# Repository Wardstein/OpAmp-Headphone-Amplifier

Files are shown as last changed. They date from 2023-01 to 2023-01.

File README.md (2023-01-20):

# Headphone Amplifier with 24bit DAC
A (massive) parallel OpAmp headphone amplifier using 16 parallel OpAmps per channel. The complete box has three PCBs: the power supply, a 24bit DAC with USB interface and the amplifier board itself (hidden under the black heatsink).

<p float="center">
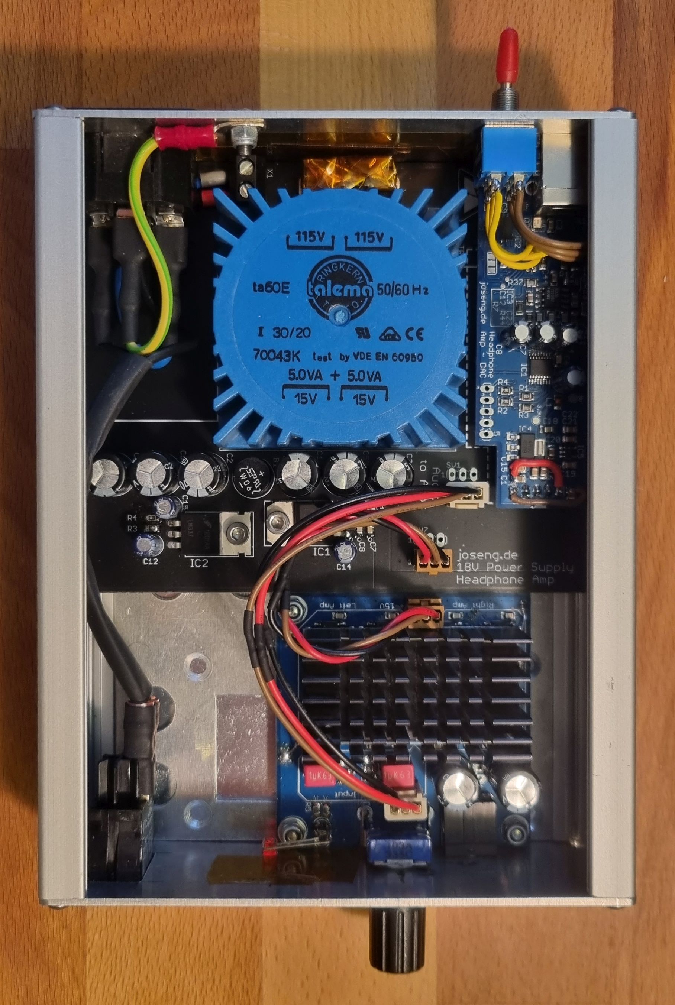
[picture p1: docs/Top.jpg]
Amplifier Top
  
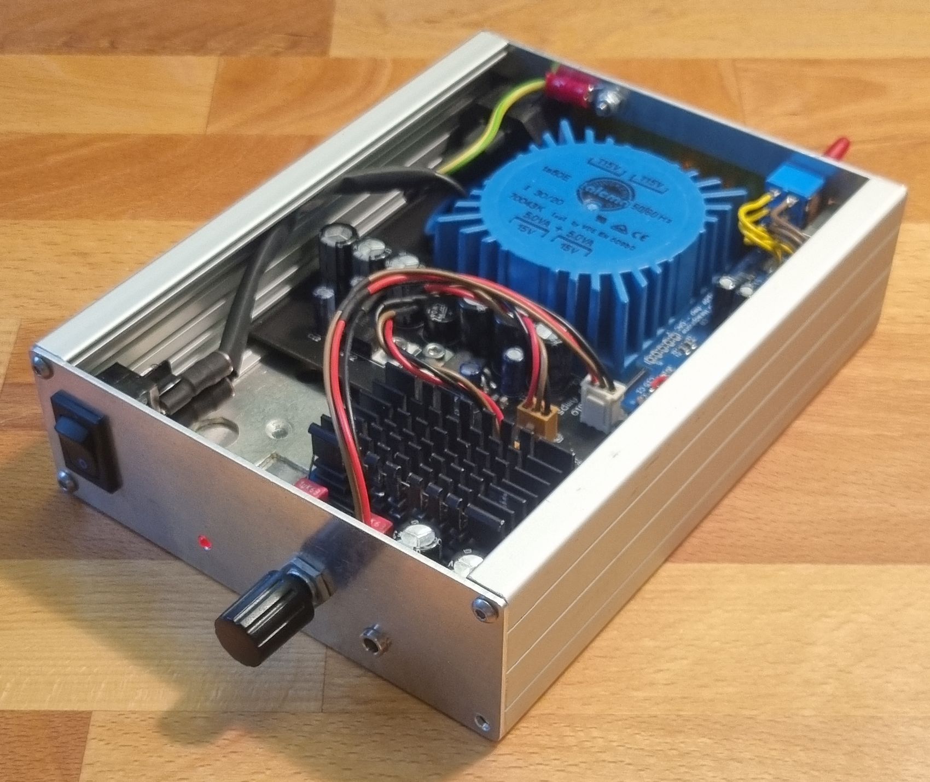
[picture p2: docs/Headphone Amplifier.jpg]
Headphone Amplifier
  
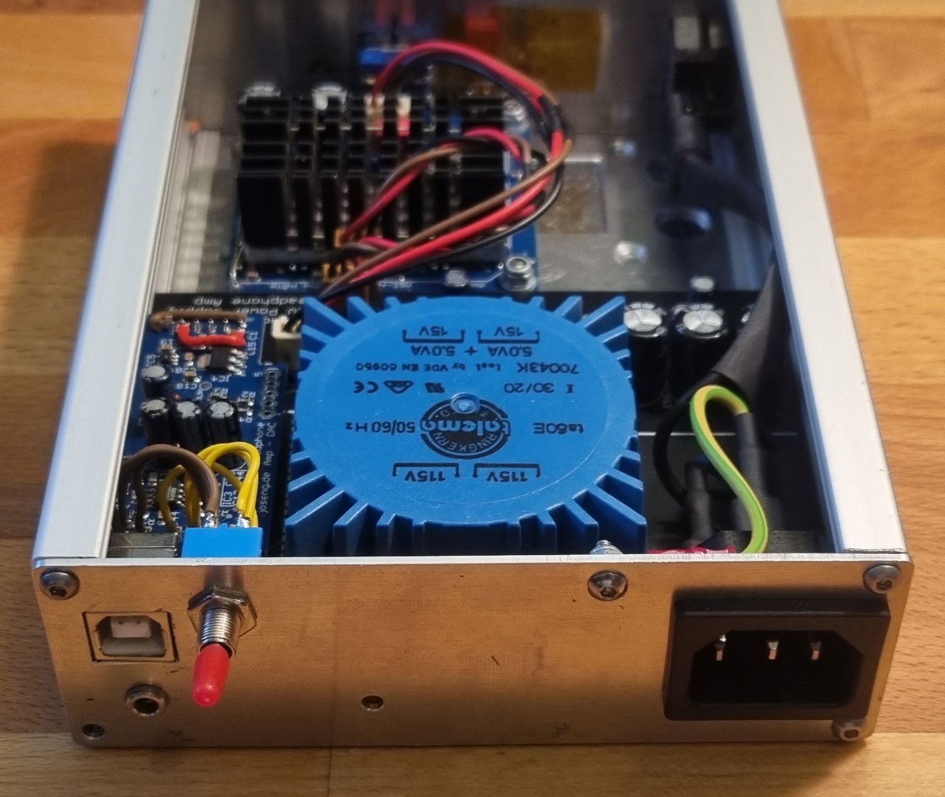
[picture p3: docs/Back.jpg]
Amplifier Back
   
</p>

The amplifier PSU "base board" has an input for analog signals which can be routed to the amp board, or there can be a USB DAC board plugged in. When you want to switch between analog and USB input, you need to solder a switch to the base board connections of the DAC board (see in the pictures above).

# Noise
The reasoning behind the paralleling so much opamps is to decrease the noise during amplification and therefore improve the SNR. When using this headphone amp with the USB DAC board, we want to give some credit to the 24bit DAC and make the amp as low noise as possible.

In theory the noise is multiplied by the square root of N (number of amplifiers), instead of the number of amplifiers like the gain. Here is a good read: https://www.analog.com/en/technical-articles/paralleling-amplifiers-improves-signal-to-noise-performance.html

This is also the reasoning for the torodial transformer and the linear power supply.

One drawback of the parallel OpAmps is the waste heat, generated by the chips as they are driving their outputs against each other. Typically audio amplifiers are not "high precision" amps in terms of DC offset voltages, so each OpAmp has a different offset and therefore they all drive a bit of current all the time.

# Setting up the CP2114-B02 USB-I2S Bridge chip
Poorly the CP2114-B02 is also obsolete and I could not find any other replacement chip for USB to I2S which offers 24bit support. ONLY the -B02 version offers 24bit support. Maybe one can replace it with some Cypress FX2/FX3 chips or an AVR/SAM with a USB audio device firmware.

Anyways, how to configure the existing CP2114-B02: It has a One-Time Programmable ROM (chapter 3.6 in the datasheet), where config slots can be programmed with a PC tool. These slots contain information about clocking, audio data format and so on. The config is selected at startup by some bootstrapping pins, which means we do not have to configure the CP2114 with an MCU after we programmed it with the PC.

Steps to program the config:

1. Extract the PC utility called CP21xxCustomizationUtility from AN721SW.zip file, for your operating system
2. Connect the DAC board/the CP2114 via USB and power it up (could be in this headphone amplifier, or in your custom circuit)
3. Load the finished configuration from the file "ConfigData_24bit.txt" and click the "Program Device" button.

Ensure you selected the right config at the first time of programming, as each slot can only be written once. The next program cycle will write to the next slot, and you have to change then the config bootstrapping pin resistors to select the right config slot at startup!

After programming the chip, you need to uninstall it in the device manager and replug it, at least under windows, to make the new config take effect.

Some link collection used during the config creation:

* Only 24bit playback or recording at a time:
  * https://community.silabs.com/s/article/cp2114-b02-24-bit-record-playback-vs-16-bit-record-playback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
  * https://community.silabs.com/s/article/cp2114-b02-audio-24-bit-mode?language=en_US
  * https://community.silabs.com/s/question/0D51M00007xeOMqSAM/does-the-cp2114b02-support-true-24-bits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
* Bad noise (happend to me also), taken care in the config
  * https://community.silabs.com/s/question/0D51M00007xeE9cSAE/cp2114-crackling-or-choppy-noise?language=en_US
  * https://community.silabs.com/s/article/cp2114-and-asynchronous-mode?language=en_US
  * https://www.silabs.com/documents/public/errata/cp2114-errata.pdf chapter 3.2.1
* Distinguishing chip version: https://community.silabs.com/s/article/cp2114-b01-vs-b02-package-marking-1?language=en_US

# Replacement for the obsolete OPA2604
The internet delivers multiple alternatives for the obsolete OPA2604:
* OPA2134 (need to make sure the PSU PCB is tuned to +-15V!)
* OPA2227 (need to make sure the PSU PCB is tuned to +-15V!)
* OPA1642
* NE5534A (not a double opamp, not pin compatible)

Source: http://www.hifi-forum.de/viewthread-71-13538.html (german). Also with some good noise comparison charts.

# Housing
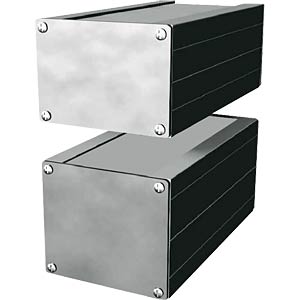
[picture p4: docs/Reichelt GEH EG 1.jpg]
Housing Electronic Load


The housing is a proMa "Euro-Gehäuse EG 1" article number "131 020", e.g. available at [Reichelt](https://www.reichelt.de/de/en/euro-casing-geh-eg-1-p50423.html). The front and back are custom 3D prints. The front panel PCB is also custom made exactly for this housing, but is fairly easy modified for any other housing front.

# License
The content of this whole repository is licensed under [CERN-OHL-W v2](License/cern_ohl_w_v2.txt) or later by Jonas Eberhard.

Excepted is the software copied from Cypress in the AN721SW.zip file. This was copied to this repo for archiving purpose!

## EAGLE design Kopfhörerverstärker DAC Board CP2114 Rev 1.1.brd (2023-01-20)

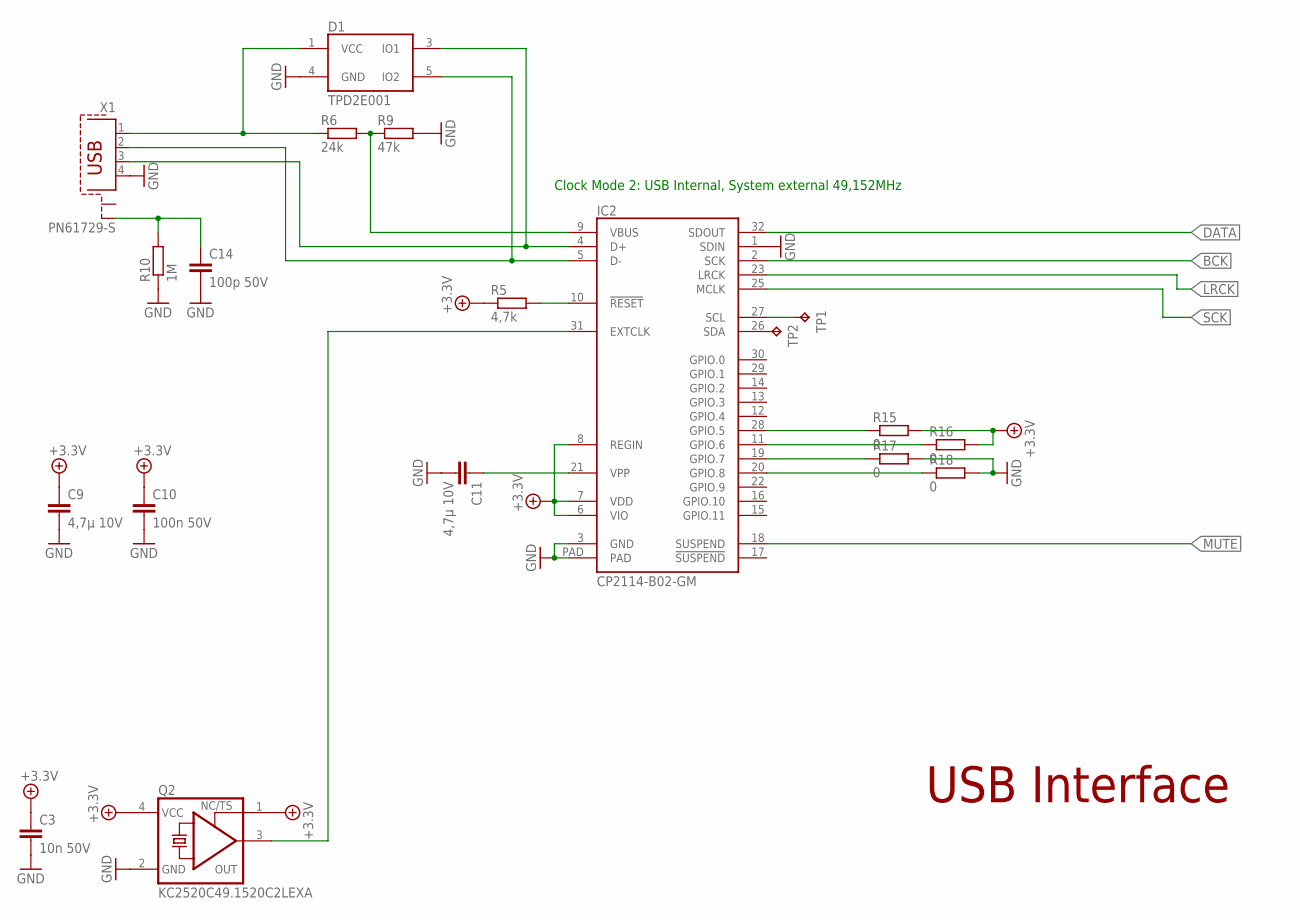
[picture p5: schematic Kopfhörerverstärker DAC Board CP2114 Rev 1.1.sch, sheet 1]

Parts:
C3: 10n 50V; C0805
C9, C11: 4,7µ 10V; C0805
C10: 100n 50V; C0805
C14: 100p 50V; C0805
D1: TPD2E001; SOT-5X3_R-PDSO-N5-DRL
IC2: CP2114-B02-GM; QFN32
Q2: KC2520C49.1520C2LEXA; 2.5X2.0
R5: 4,7k; R0805
R6: 24k; R0805
R9: 47k; R0805
R10: 1M; R0805
R15, R16, R17, R18: 0; R0805
TP1, TP2: TPTP10R; TP10R
X1: PN61729-S

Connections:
+3,3V: C3.1, C9.1, C10.1, IC2.6 (VIO), IC2.7 (VDD), IC2.8 (REGIN), Q2.1 (TS), Q2.4 (VCC), R5.1, R15.2, R16.2; also elsewhere on the board
BCK: IC2.2 (SCK); also elsewhere on the board
DATA: IC2.32 (SDOUT); also elsewhere on the board
GND: C3.2, C9.2, C10.2, C11.2, C14.2, D1.4 (GND), IC2.1 (SDIN), IC2.3 (GND), IC2.PAD, Q2.2 (GND), R9.2, R10.1, R17.2, R18.2, X1.4; also elsewhere on the board
LRCK: IC2.23 (LRCK); also elsewhere on the board
MUTE: IC2.18 (SUSPEND); also elsewhere on the board
unnamed: IC2.28 (GPIO.5), R15.1
unnamed: IC2.31 (EXTCLK), Q2.3 (OUT)
unnamed: IC2.9 (VBUS), R6.2, R9.1
unnamed: C11.1, IC2.21 (VPP)
unnamed: IC2.10 (!RESET), R5.2
unnamed: C14.1, R10.2, X1.S2
unnamed: D1.5 (IO2), IC2.5 (D-), X1.2
unnamed: D1.3 (IO1), IC2.4 (D+), X1.3
unnamed: D1.1 (VCC), R6.1, X1.1
unnamed: IC2.27 (SCL), TP1.TP
unnamed: IC2.26 (SDA), TP2.TP
unnamed: IC2.11 (GPIO.6), R16.1
unnamed: IC2.19 (GPIO.7), R17.1
unnamed: IC2.20 (GPIO.8), R18.1
SCK: IC2.25 (MCLK); also elsewhere on the board

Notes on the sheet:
USB Interface
Clock Mode 2: USB Internal, System external 49,152MHz

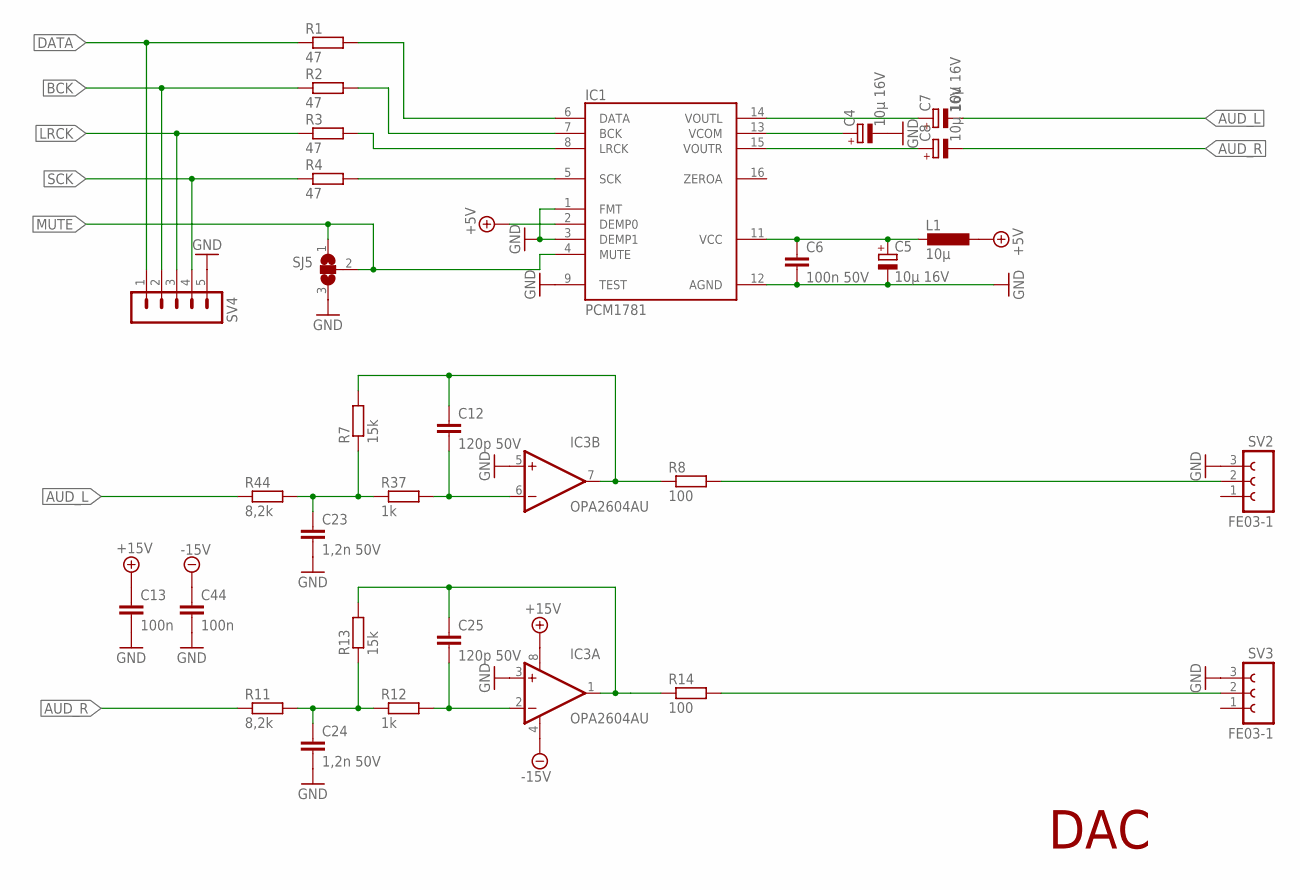
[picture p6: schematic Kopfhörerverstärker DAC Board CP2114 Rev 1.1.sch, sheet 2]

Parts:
C4, C5, C7, C8: 10µ 16V; E2,5-5
C6: 100n 50V; C0805
C12, C25: 120p 50V; C0805
C13, C44: 100n; C0805
C23, C24: 1,2n 50V; C0805
IC1: PCM1781; PW_R-PDSO-G16
IC3: OPA2604AU; SO08
L1: 10µ; L0805
R1, R2, R3, R4: 47; R0805
R7, R13: 15k; R0805
R8, R14: 100; R0805
R11, R44: 8,2k; R0805
R12, R37: 1k; R0805
SJ5: SJ2W; SJ_2
SV2, SV3: FE03-1
SV4: MA05-1

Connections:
+5V: IC1.2 (DEMP0), L1.1; also elsewhere on the board
+15V: C13.1, IC3.8 (V+); also elsewhere on the board
-15V: C44.1, IC3.4 (V-); also elsewhere on the board
AUD_L: C7.-, R44.1
AUD_R: C8.-, R11.1
BCK: R2.1, SV4.2; also elsewhere on the board
DATA: R1.1, SV4.1; also elsewhere on the board
GND: C4.-, C5.-, C6.2, C13.2, C23.2, C24.2, C44.2, IC1.1 (FMT), IC1.3 (DEMP1), IC1.9 (TEST), IC1.12 (AGND), IC3.3 (+IN), IC3.5 (+IN), SJ5.3, SV2.3, SV3.3, SV4.5; also elsewhere on the board
LRCK: R3.1, SV4.3; also elsewhere on the board
MUTE: IC1.4 (MUTE), SJ5.1, SJ5.2; also elsewhere on the board
unnamed: C23.1, R7.1, R37.1, R44.2
unnamed: C8.+, IC1.15 (VOUTR)
unnamed: C7.+, IC1.14 (VOUTL)
unnamed: IC1.6 (DATA), R1.2
unnamed: IC1.7 (BCK), R2.2
unnamed: IC1.8 (LRCK), R3.2
unnamed: IC1.5 (SCK), R4.2
unnamed: C5.+, C6.1, IC1.11 (VCC), L1.2
unnamed: C4.+, IC1.13 (VCOM)
unnamed: C25.1, IC3.1 (OUT), R13.2, R14.1
unnamed: R14.2, SV3.2
unnamed: C12.2, IC3.6 (-IN), R37.2
unnamed: C12.1, IC3.7 (OUT), R7.2, R8.1
unnamed: R8.2, SV2.2
unnamed: C25.2, IC3.2 (-IN), R12.2
unnamed: C24.1, R11.2, R12.1, R13.1
SCK: R4.1, SV4.4; also elsewhere on the board

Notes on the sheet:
DAC

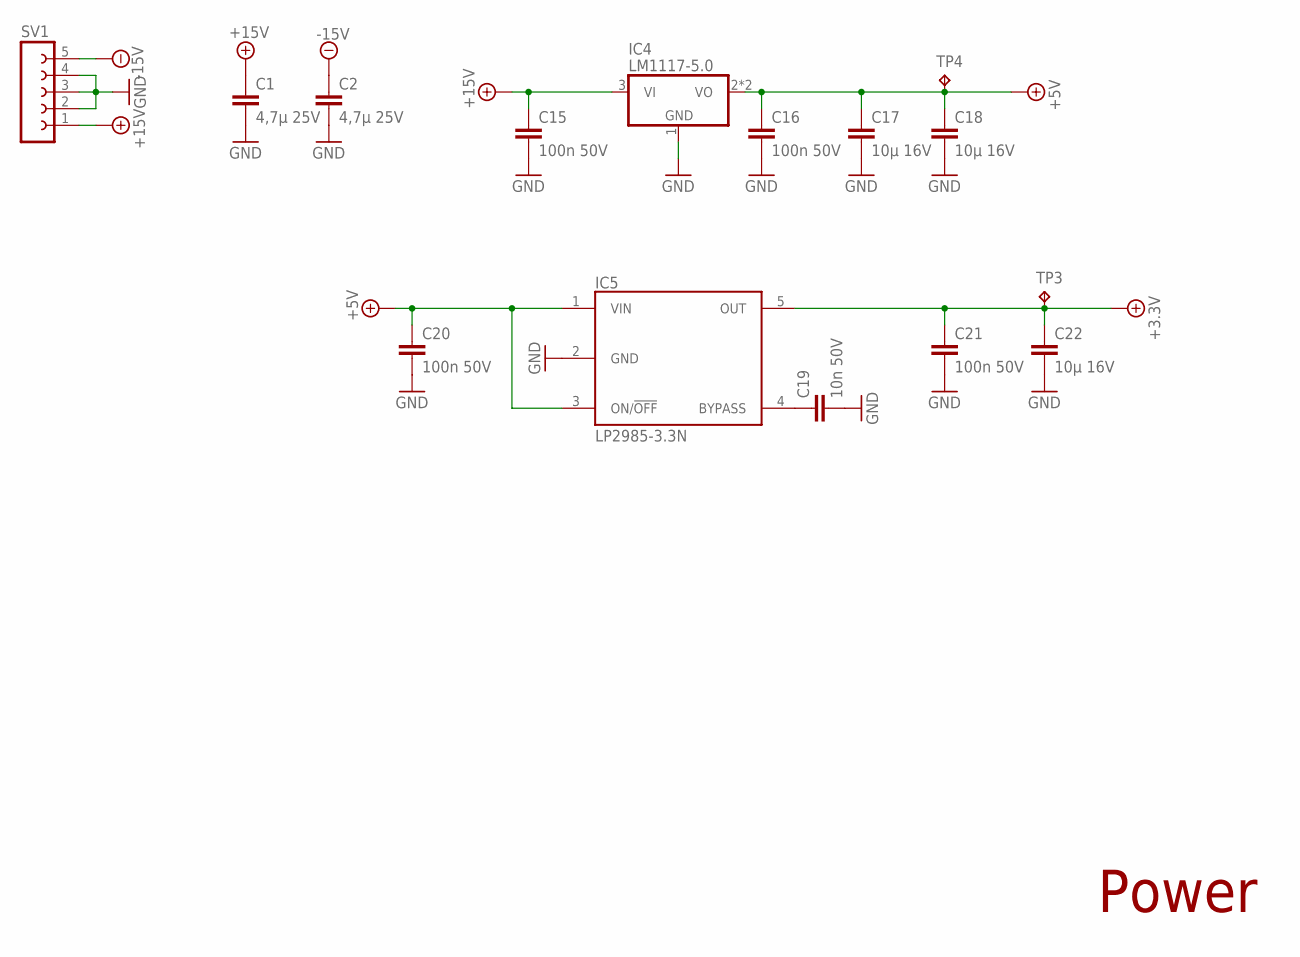
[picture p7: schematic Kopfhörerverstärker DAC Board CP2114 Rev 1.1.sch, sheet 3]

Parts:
C1, C2: 4,7µ 25V; C0805
C15, C16, C20, C21: 100n 50V; C0805
C17, C18, C22: 10µ 16V; C0805
C19: 10n 50V; C0805
IC4: LM1117-5.0; SOT223
IC5: LP2985-3.3N; SOT23-DBV
SV1: FE05-1
TP3, TP4: TPTP15R; TP15R

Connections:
+3,3V: C21.1, C22.1, IC5.5 (OUT), TP3.TP; also elsewhere on the board
+5V: C16.1, C17.1, C18.1, C20.1, IC4.2 (VO), IC4.4 (VO), IC5.1 (VIN), IC5.3 (ON/!OFF), TP4.TP; also elsewhere on the board
+15V: C1.1, C15.1, IC4.3 (VI), SV1.1; also elsewhere on the board
-15V: C2.1, SV1.5; also elsewhere on the board
GND: C1.2, C2.2, C15.2, C16.2, C17.2, C18.2, C19.2, C20.2, C21.2, C22.2, IC4.1 (GND), IC5.2 (GND), SV1.2, SV1.3, SV1.4; also elsewhere on the board
unnamed: C19.1, IC5.4 (BYPASS)

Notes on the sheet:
Power

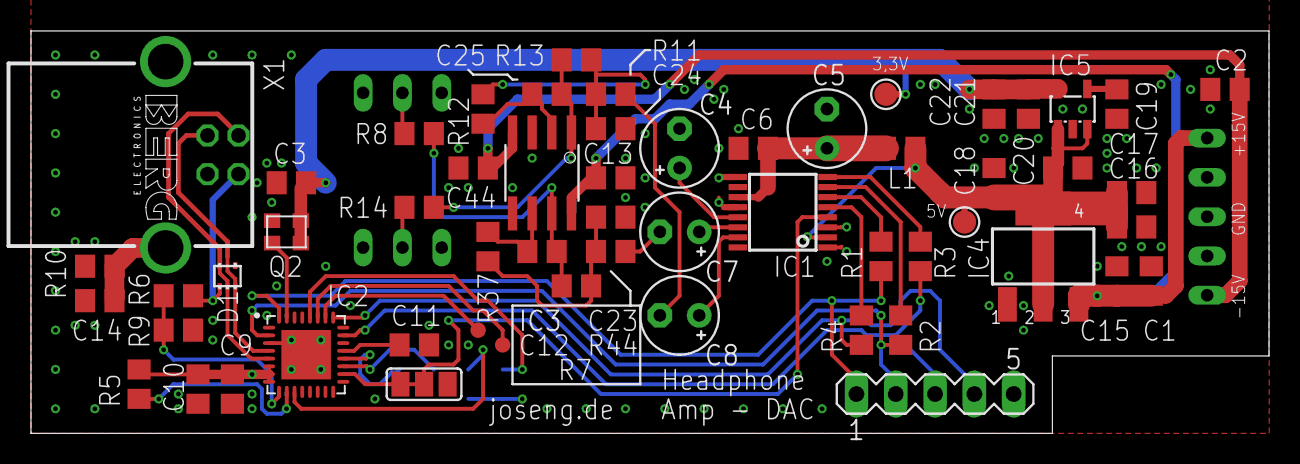
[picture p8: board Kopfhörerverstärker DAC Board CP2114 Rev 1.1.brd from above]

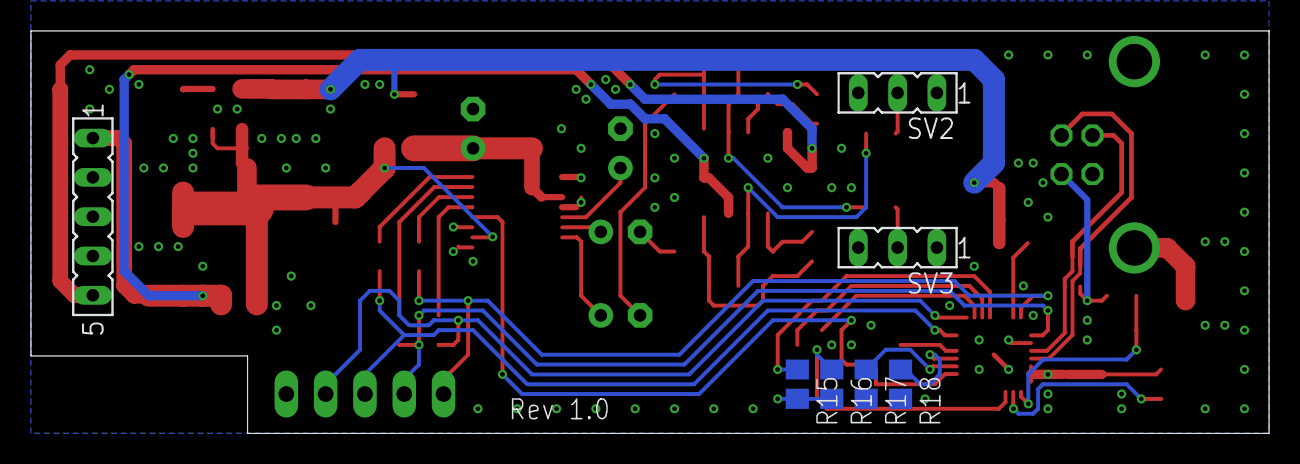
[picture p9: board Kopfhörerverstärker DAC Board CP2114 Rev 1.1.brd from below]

Board: 4 copper layers, 80.0 x 26.0 mm, 64 parts (7 on the bottom side), 43 nets.

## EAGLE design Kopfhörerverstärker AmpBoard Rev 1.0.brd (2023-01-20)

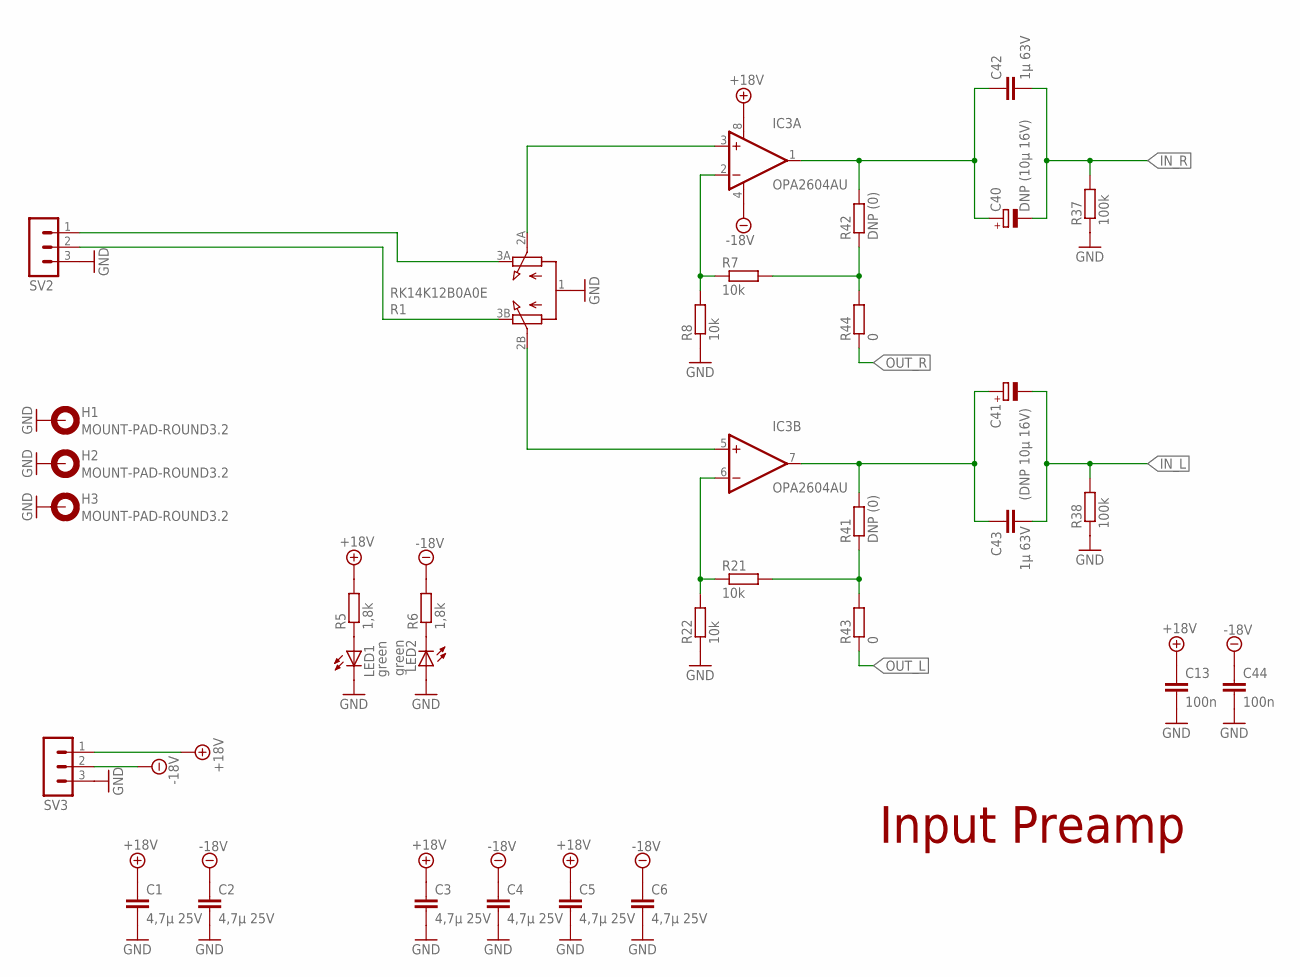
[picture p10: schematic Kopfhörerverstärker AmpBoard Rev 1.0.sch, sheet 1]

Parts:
C1, C2, C3, C4, C5, C6: 4,7µ 25V; C0805
C13, C44: 100n; C0805
C40: DNP (10µ 16V); E2,5-5
C41: (DNP 10µ 16V); E2,5-5
C42, C43: 1µ 63V; C050-050X075
H1, H2, H3: MOUNT-PAD-ROUND3.2; 3,2-PAD
IC3: OPA2604AU; SO08
LED1, LED2: green; LED3MM
R1: RK14K12B0A0E; RK14K12
R5, R6: 1,8k; R0805
R7, R8, R21, R22: 10k; R0805
R37, R38: 100k; R0805
R41, R42: DNP (0); R0805
R43, R44: 0; R0805
SV2, SV3: MA03-1

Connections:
+18V: C1.1, C3.1, C5.1, C13.1, IC3.8 (V+), R5.2, SV3.1; also elsewhere on the board
-18V: C2.1, C4.1, C6.1, C44.1, IC3.4 (V-), R6.2, SV3.2; also elsewhere on the board
GND: C1.2, C2.2, C3.2, C4.2, C5.2, C6.2, C13.2, C44.2, H1.B3,2, H2.B3,2, H3.B3,2, LED1.K (C), LED2.A, R1.1, R8.1, R22.1, R37.1, R38.1, SV2.3, SV3.3; also elsewhere on the board
IN_L: C41.-, C43.2, R38.2; also elsewhere on the board
IN_R: C40.-, C42.2, R37.2; also elsewhere on the board
unnamed: R1.3A, SV2.1
unnamed: R1.3B, SV2.2
unnamed: LED1.A, R5.1
unnamed: LED2.K (C), R6.1
unnamed: IC3.2 (-IN), R7.1, R8.2
unnamed: C40.+, C42.1, IC3.1 (OUT), R42.2
unnamed: IC3.6 (-IN), R21.1, R22.2
unnamed: IC3.5 (+IN), R1.2B
unnamed: IC3.3 (+IN), R1.2A
unnamed: R21.2, R41.1, R43.2
unnamed: R7.2, R42.1, R44.2
unnamed: C41.+, C43.1, IC3.7 (OUT), R41.2
OUT_L: R43.1; also elsewhere on the board
OUT_R: R44.1; also elsewhere on the board

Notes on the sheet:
Input Preamp

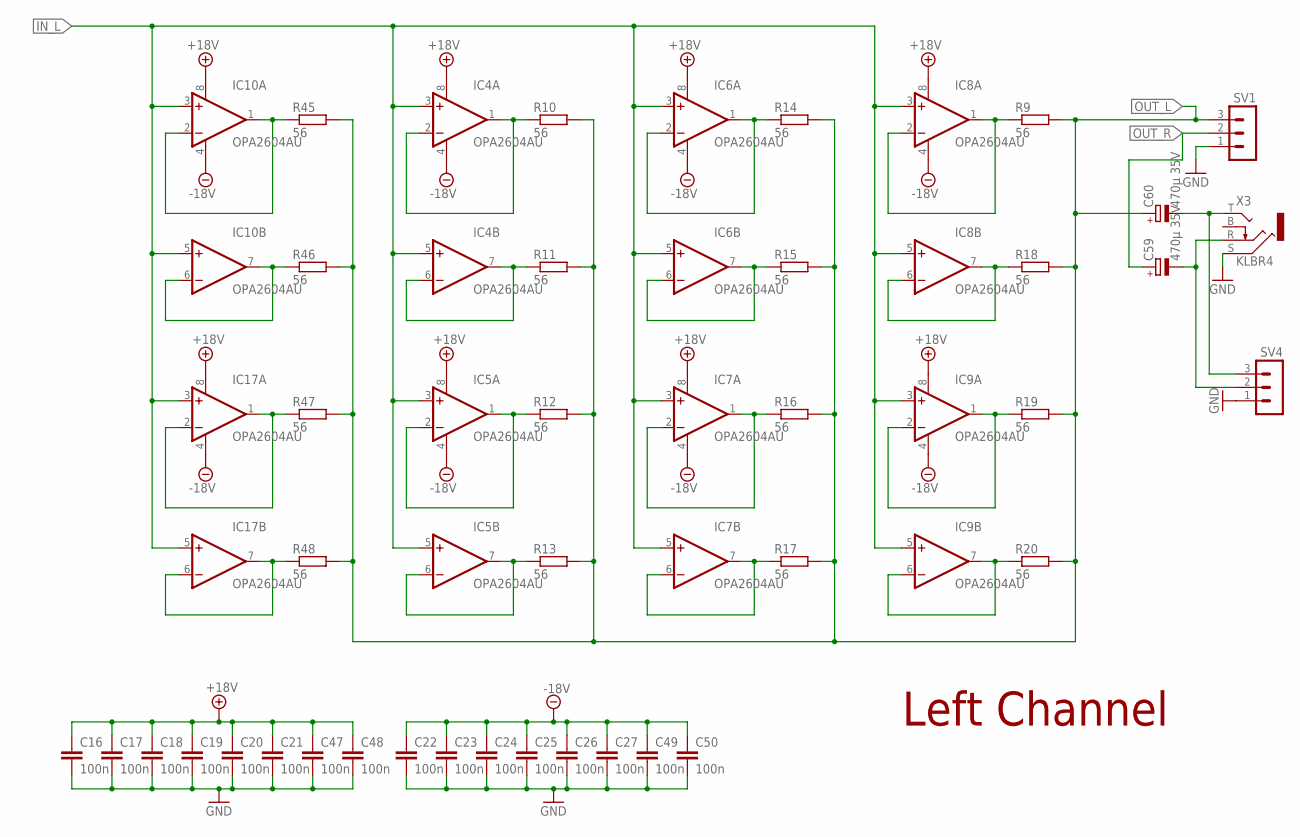
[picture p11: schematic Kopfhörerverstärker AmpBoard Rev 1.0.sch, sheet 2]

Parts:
C16, C17, C18, C19, C20, C21, C22, C23, C24, C25, C26, C27, C47, C48, C49, C50: 100n; C0805
C59, C60: 470µ 35V; E5-10,5
IC4, IC5, IC6, IC7, IC8, IC9, IC10, IC17: OPA2604AU; SO08
R9, R10, R11, R12, R13, R14, R15, R16, R17, R18, R19, R20, R45, R46, R47, R48: 56; R0805
SV1, SV4: MA03-1
X3: KLBR4

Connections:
+18V: C16.1, C17.1, C18.1, C19.1, C20.1, C21.1, C47.1, C48.1, IC4.8 (V+), IC5.8 (V+), IC6.8 (V+), IC7.8 (V+), IC8.8 (V+), IC9.8 (V+), IC10.8 (V+), IC17.8 (V+); also elsewhere on the board
-18V: C22.1, C23.1, C24.1, C25.1, C26.1, C27.1, C49.1, C50.1, IC4.4 (V-), IC5.4 (V-), IC6.4 (V-), IC7.4 (V-), IC8.4 (V-), IC9.4 (V-), IC10.4 (V-), IC17.4 (V-); also elsewhere on the board
GND: C16.2, C17.2, C18.2, C19.2, C20.2, C21.2, C22.2, C23.2, C24.2, C25.2, C26.2, C27.2, C47.2, C48.2, C49.2, C50.2, SV1.1, SV4.1, X3.S; also elsewhere on the board
IN_L: IC4.3 (+IN), IC4.5 (+IN), IC5.3 (+IN), IC5.5 (+IN), IC6.3 (+IN), IC6.5 (+IN), IC7.3 (+IN), IC7.5 (+IN), IC8.3 (+IN), IC8.5 (+IN), IC9.3 (+IN), IC9.5 (+IN), IC10.3 (+IN), IC10.5 (+IN), IC17.3 (+IN), IC17.5 (+IN); also elsewhere on the board
unnamed: C59.-, SV4.2, X3.R
unnamed: C60.-, SV4.3, X3.T
unnamed: IC4.6 (-IN), IC4.7 (OUT), R11.1
unnamed: IC5.1 (OUT), IC5.2 (-IN), R12.1
unnamed: IC8.1 (OUT), IC8.2 (-IN), R9.1
unnamed: IC4.1 (OUT), IC4.2 (-IN), R10.1
unnamed: IC5.6 (-IN), IC5.7 (OUT), R13.1
unnamed: IC6.1 (OUT), IC6.2 (-IN), R14.1
unnamed: IC6.6 (-IN), IC6.7 (OUT), R15.1
unnamed: IC7.1 (OUT), IC7.2 (-IN), R16.1
unnamed: IC7.6 (-IN), IC7.7 (OUT), R17.1
unnamed: IC8.6 (-IN), IC8.7 (OUT), R18.1
unnamed: IC9.1 (OUT), IC9.2 (-IN), R19.1
unnamed: IC9.6 (-IN), IC9.7 (OUT), R20.1
unnamed: IC10.1 (OUT), IC10.2 (-IN), R45.1
unnamed: IC10.6 (-IN), IC10.7 (OUT), R46.1
unnamed: IC17.1 (OUT), IC17.2 (-IN), R47.1
unnamed: IC17.6 (-IN), IC17.7 (OUT), R48.1
OUT_L: C60.+, R9.2, R10.2, R11.2, R12.2, R13.2, R14.2, R15.2, R16.2, R17.2, R18.2, R19.2, R20.2, R45.2, R46.2, R47.2, R48.2, SV1.3; also elsewhere on the board
OUT_R: C59.+, SV1.2; also elsewhere on the board

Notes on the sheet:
Left Channel

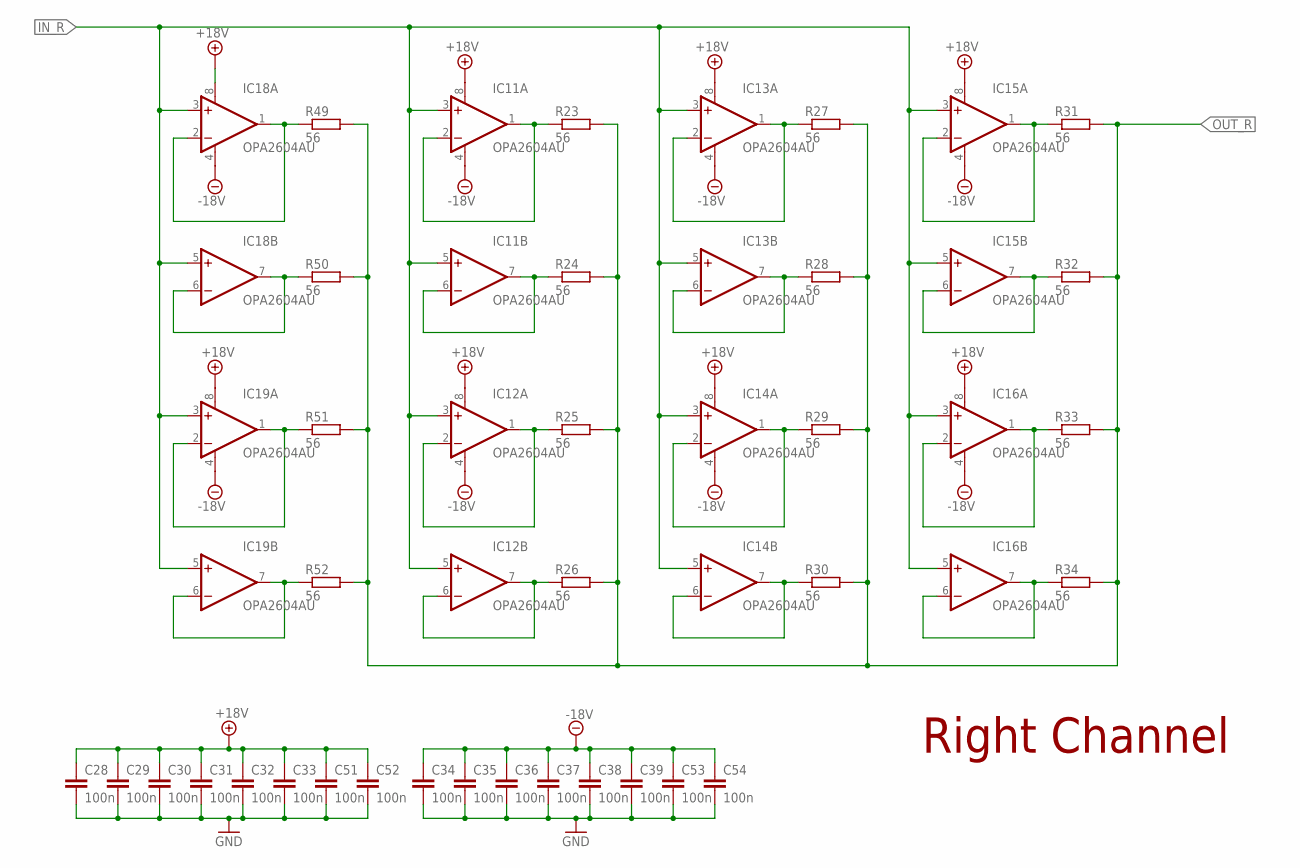
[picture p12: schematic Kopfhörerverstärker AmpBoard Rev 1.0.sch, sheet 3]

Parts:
C28, C29, C30, C31, C32, C33, C34, C35, C36, C37, C38, C39, C51, C52, C53, C54: 100n; C0805
IC11, IC12, IC13, IC14, IC15, IC16, IC18, IC19: OPA2604AU; SO08
R23, R24, R25, R26, R27, R28, R29, R30, R31, R32, R33, R34, R49, R50, R51, R52: 56; R0805

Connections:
+18V: C28.1, C29.1, C30.1, C31.1, C32.1, C33.1, C51.1, C52.1, IC11.8 (V+), IC12.8 (V+), IC13.8 (V+), IC14.8 (V+), IC15.8 (V+), IC16.8 (V+), IC18.8 (V+), IC19.8 (V+); also elsewhere on the board
-18V: C34.1, C35.1, C36.1, C37.1, C38.1, C39.1, C53.1, C54.1, IC11.4 (V-), IC12.4 (V-), IC13.4 (V-), IC14.4 (V-), IC15.4 (V-), IC16.4 (V-), IC18.4 (V-), IC19.4 (V-); also elsewhere on the board
GND: C28.2, C29.2, C30.2, C31.2, C32.2, C33.2, C34.2, C35.2, C36.2, C37.2, C38.2, C39.2, C51.2, C52.2, C53.2, C54.2; also elsewhere on the board
IN_R: IC11.3 (+IN), IC11.5 (+IN), IC12.3 (+IN), IC12.5 (+IN), IC13.3 (+IN), IC13.5 (+IN), IC14.3 (+IN), IC14.5 (+IN), IC15.3 (+IN), IC15.5 (+IN), IC16.3 (+IN), IC16.5 (+IN), IC18.3 (+IN), IC18.5 (+IN), IC19.3 (+IN), IC19.5 (+IN); also elsewhere on the board
unnamed: IC11.1 (OUT), IC11.2 (-IN), R23.1
unnamed: IC11.6 (-IN), IC11.7 (OUT), R24.1
unnamed: IC12.1 (OUT), IC12.2 (-IN), R25.1
unnamed: IC12.6 (-IN), IC12.7 (OUT), R26.1
unnamed: IC13.1 (OUT), IC13.2 (-IN), R27.1
unnamed: IC13.6 (-IN), IC13.7 (OUT), R28.1
unnamed: IC14.1 (OUT), IC14.2 (-IN), R29.1
unnamed: IC14.6 (-IN), IC14.7 (OUT), R30.1
unnamed: IC15.1 (OUT), IC15.2 (-IN), R31.1
unnamed: IC15.6 (-IN), IC15.7 (OUT), R32.1
unnamed: IC16.1 (OUT), IC16.2 (-IN), R33.1
unnamed: IC16.6 (-IN), IC16.7 (OUT), R34.1
unnamed: IC18.1 (OUT), IC18.2 (-IN), R49.1
unnamed: IC18.6 (-IN), IC18.7 (OUT), R50.1
unnamed: IC19.1 (OUT), IC19.2 (-IN), R51.1
unnamed: IC19.6 (-IN), IC19.7 (OUT), R52.1
OUT_R: R23.2, R24.2, R25.2, R26.2, R27.2, R28.2, R29.2, R30.2, R31.2, R32.2, R33.2, R34.2, R49.2, R50.2, R51.2, R52.2; also elsewhere on the board

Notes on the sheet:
Right Channel

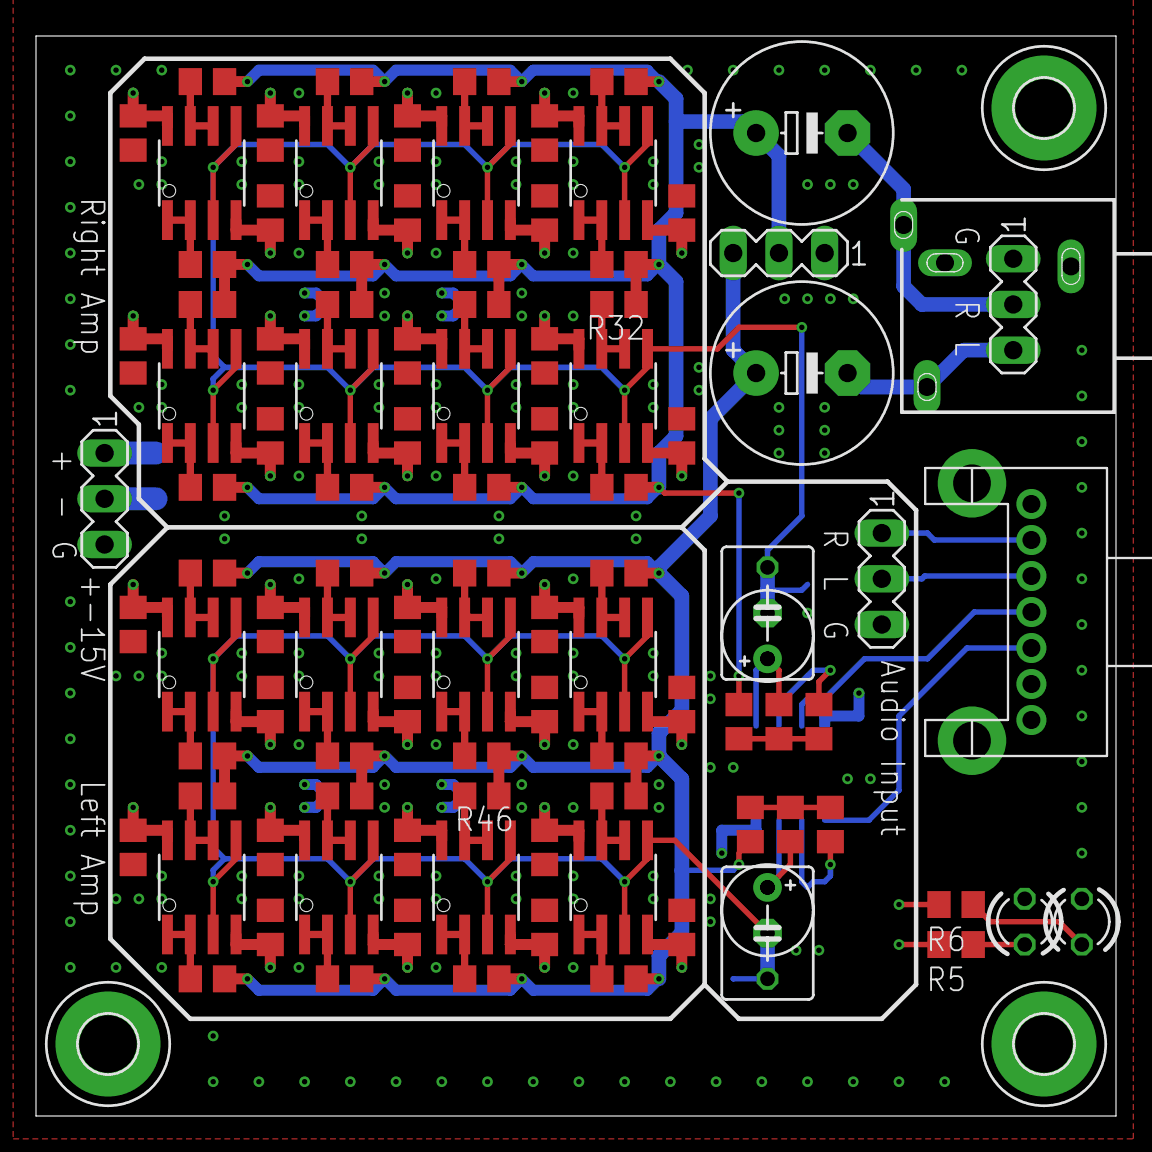
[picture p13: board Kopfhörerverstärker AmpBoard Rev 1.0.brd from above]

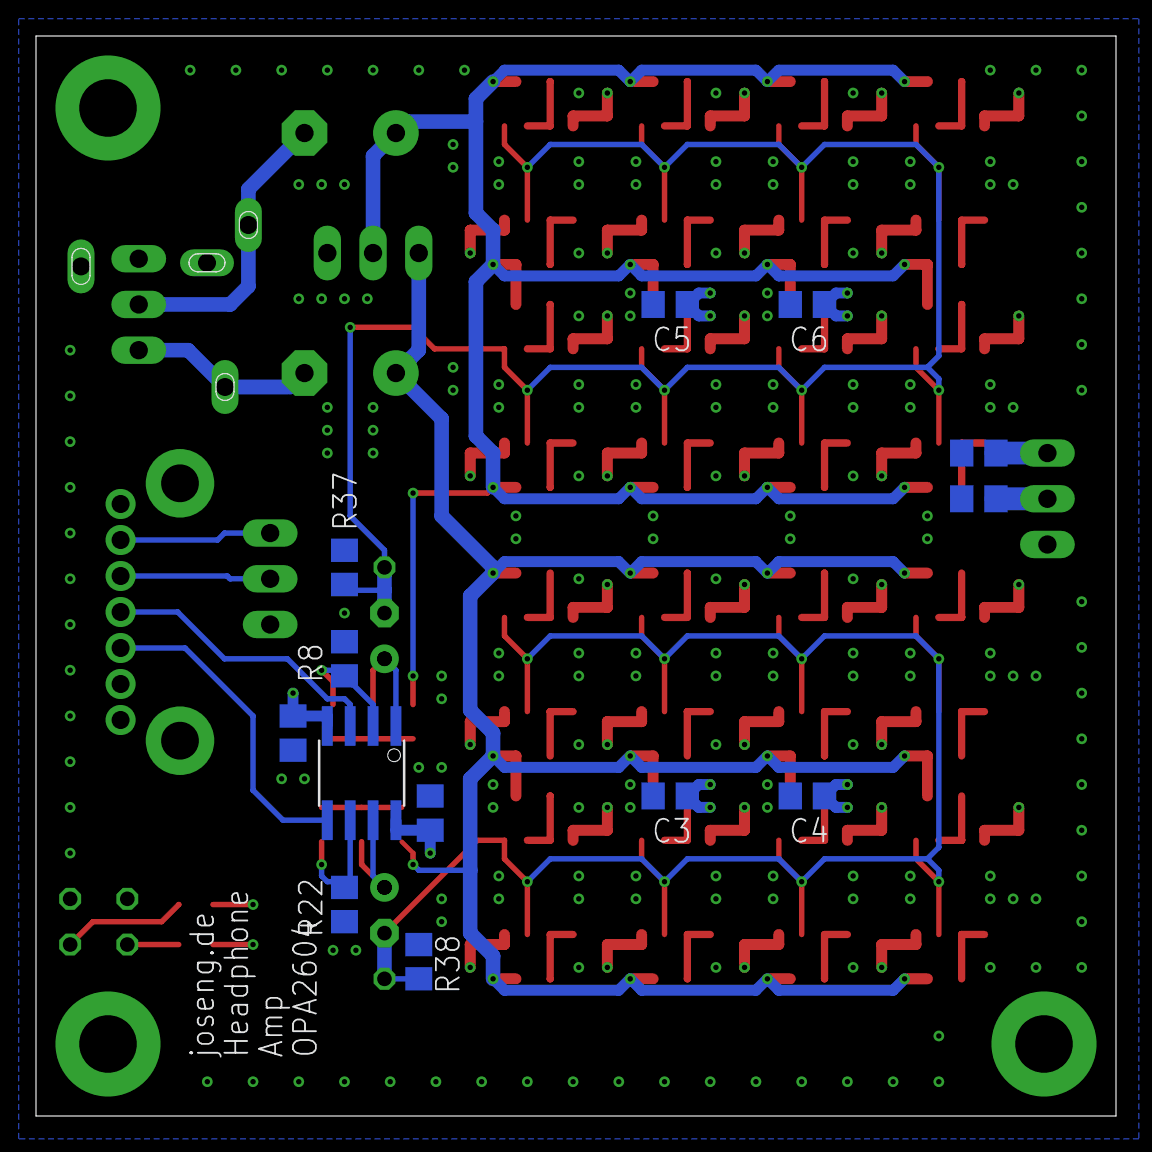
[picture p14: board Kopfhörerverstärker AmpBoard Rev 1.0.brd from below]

Board: 4 copper layers, 60.0 x 60.0 mm, 118 parts (13 on the bottom side), 53 nets.

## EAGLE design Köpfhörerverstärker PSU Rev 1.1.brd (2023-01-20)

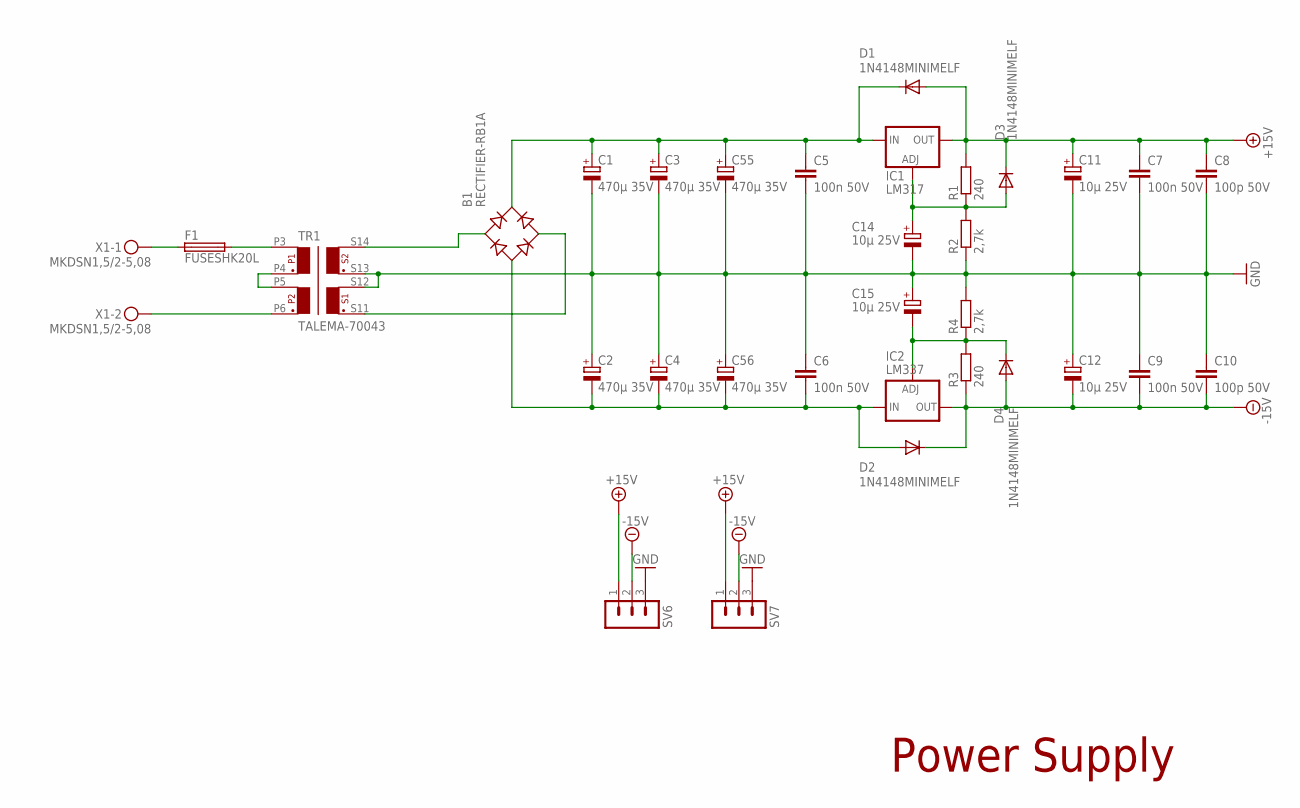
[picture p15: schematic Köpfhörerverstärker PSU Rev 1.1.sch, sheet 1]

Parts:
B1: RECTIFIER-RB1A; RB1A
C1, C2, C3, C4, C55, C56: 470µ 35V; E5-10,5
C5, C6, C7, C9: 100n 50V; C0805
C8, C10: 100p 50V; C0805
C11, C12, C14, C15: 10µ 25V; E2,5-5
D1, D2, D3, D4: 1N4148MINIMELF; MINIMELF
F1: FUSESHK20L; SHK20L
IC1: LM317; 317TL
IC2: LM337; 337TL
R1, R3: 240; R0805
R2, R4: 2,7k; R0805
SV6, SV7: MA03-1
TR1: TALEMA-70043
X1: MKDSN1,5/2-5,08

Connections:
+15V: C7.1, C8.1, C11.+, D1.A, D3.C, IC1.2 (OUT), R1.2, SV6.1, SV7.1; also elsewhere on the board
-15V: C9.2, C10.2, C12.-, D2.C, D4.A, IC2.3 (OUT), R3.1, SV6.2, SV7.2; also elsewhere on the board
GND: C1.-, C2.+, C3.-, C4.+, C5.2, C6.1, C7.2, C8.2, C9.1, C10.1, C11.-, C12.+, C14.-, C15.+, C55.-, C56.+, R2.1, R4.2, SV6.3, SV7.3, TR1.S12 (6), TR1.S13 (7); also elsewhere on the board
unnamed: F1.2A (2), TR1.P3 (1)
unnamed: F1.1A (1), X1.1
unnamed: TR1.P6 (4), X1.2
unnamed: TR1.P4 (2), TR1.P5 (3)
unnamed: B1.AC2, TR1.S11 (5)
unnamed: B1.AC1, TR1.S14 (8)
unnamed: C14.+, D3.A, IC1.1 (ADJ), R1.1, R2.2
unnamed: C15.-, D4.C, IC2.1 (ADJ), R3.2, R4.1
unnamed: B1.-, C2.-, C4.-, C6.2, C56.-, D2.A, IC2.2 (IN)
unnamed: B1.+, C1.+, C3.+, C5.1, C55.+, D1.C, IC1.3 (IN)

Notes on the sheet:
Power Supply

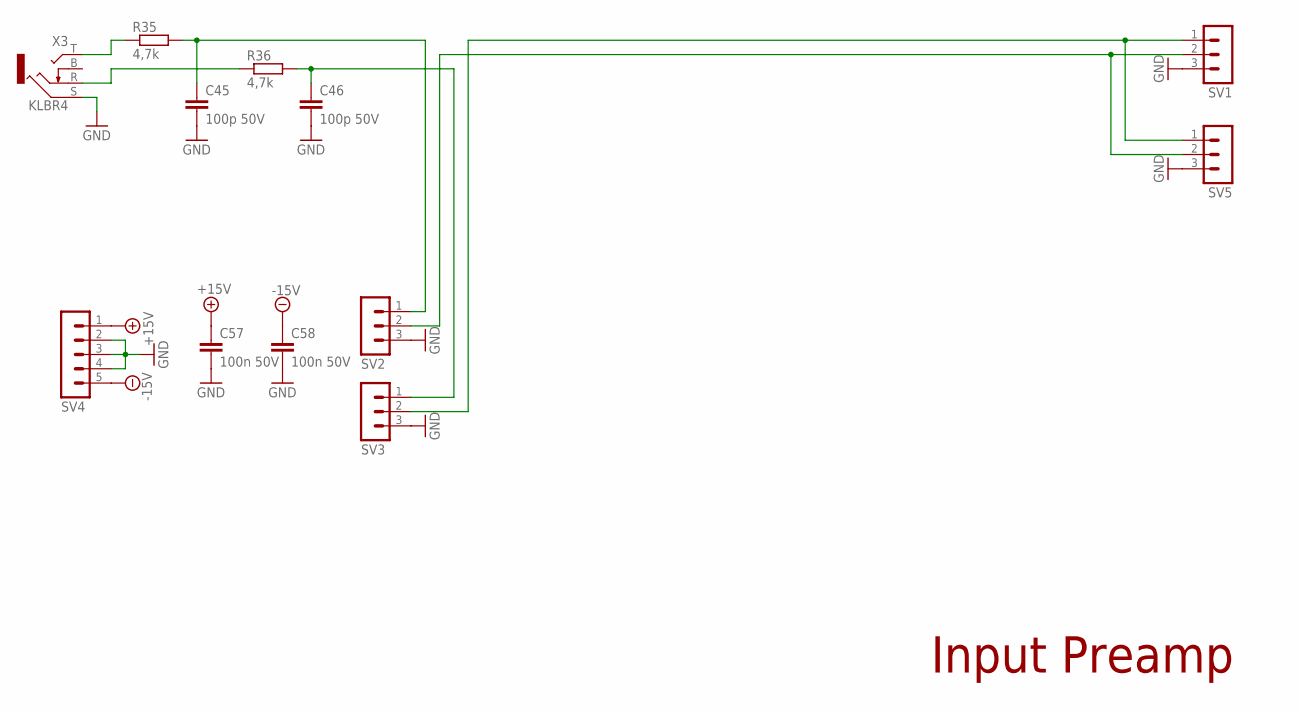
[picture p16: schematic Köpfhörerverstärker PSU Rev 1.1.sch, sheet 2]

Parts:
C45, C46: 100p 50V; C050-025X075
C57, C58: 100n 50V; C0805
R35, R36: 4,7k; R0805
SV1, SV2, SV3, SV5: MA03-1
SV4: MA05-1
X3: KLBR4

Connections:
+15V: C57.1, SV4.1; also elsewhere on the board
-15V: C58.1, SV4.5; also elsewhere on the board
GND: C45.2, C46.2, C57.2, C58.2, SV1.3, SV2.3, SV3.3, SV4.2, SV4.3, SV4.4, SV5.3, X3.S; also elsewhere on the board
unnamed: SV1.2, SV2.2, SV5.2
unnamed: R36.1, X3.R
unnamed: R35.1, X3.T
unnamed: C45.1, R35.2, SV2.1
unnamed: SV1.1, SV3.2, SV5.1
unnamed: C46.1, R36.2, SV3.1

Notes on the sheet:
Input Preamp



Board: 2 copper layers, 100.0 x 120.5 mm, 46 parts (13 on the bottom side), 19 nets.

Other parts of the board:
U$1, U$2: HIGH_VOLTAGE_10MM
